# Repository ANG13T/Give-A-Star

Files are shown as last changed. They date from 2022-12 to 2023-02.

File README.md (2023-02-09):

<div style="text-align:center" align="center">
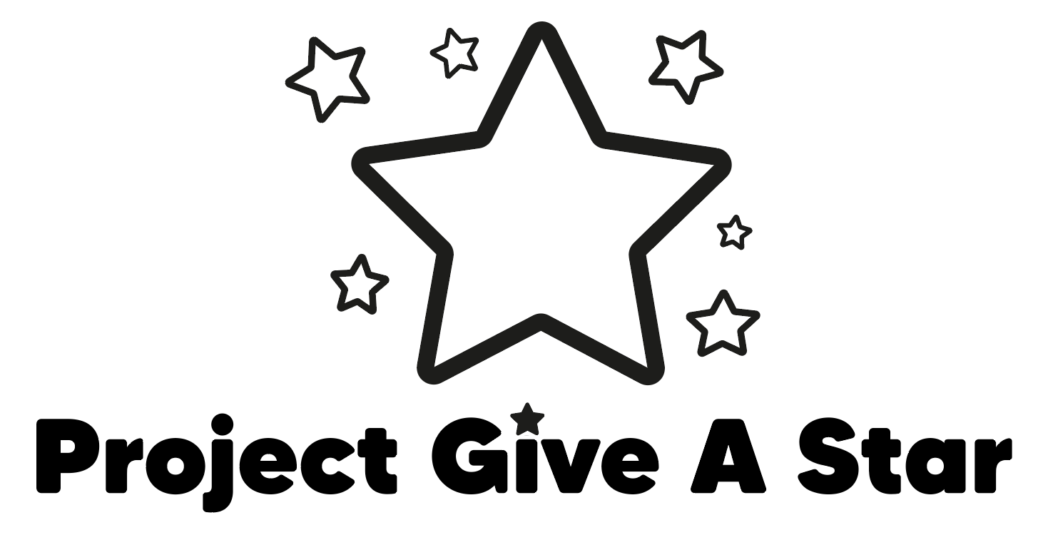
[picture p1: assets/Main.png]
Give A Star logo

</div>

<h3 style="text-align:center" align="center">A Star PCB Board based on the ESP32-S2 and D1 Mini to teach the basics of soldering</h3>

## Features
- Five Different LED Animations
- Change Animations by Clicking Button
- Teach the Basics of Soldering
- Great for Beginners

## Components
| Component | Purpose |
| --- | --- |
| **ESP32-S2** OR **ESP8266 D1 Mini** | Manage animations and code
| 128x64 SSH1106 OLED | Write a visual message to someone |
| Tactile Push Button | Change light animation |
| 6x LED | Display animations |
| 6x 100ohm Resistors | Manage voltage |

## Hardware Setup
**Top LED** 
| LED Pin | ESP32-S2 Pin | D1 Mini Pin |
| --- | --- | --- |
| VIN | 9 | D6 |
| GND | GND | GND |

**Right LED** 
| LED Pin | ESP32-S2 Pin | D1 Mini Pin |
| --- | --- | --- |
| VIN | 7 | D5 |
| GND | GND | GND |

**Bottom Right LED** 
| LED Pin | ESP32-S2 Pin | D1 Mini Pin |
| --- | --- | --- |
| VIN | 5 | D0 |
| GND | GND | GND |

**Left LED** 
| LED Pin | ESP32-S2 Pin | D1 Mini Pin |
| --- | --- | --- |
| VIN | 11 | D7 |
| GND | GND | GND |

**Bottom Left LED** 
| LED Pin | ESP32-S2 Pin | D1 Mini Pin |
| --- | --- | --- |
| VIN | 12 | D8 |
| GND | GND | GND |

**OLED SSH1106** 
| OLED Pin | ESP32-S2 Pin | D1 Mini Pin |
| --- | --- | --- |
| VCC | 3V3 | 3V3 |
| GND | GND | GND |
| SCK | 35 | D1 |
| SDA | 33 | D2 |

**Push Button** 
| Button Pin | ESP32-S2 Pin | D1 Mini Pin |
| --- | --- | --- |
| 1 | 3V3 | 3V3 |
| 2 | 16 | D4 |
| 2 | GND | GND |

## Breadboard
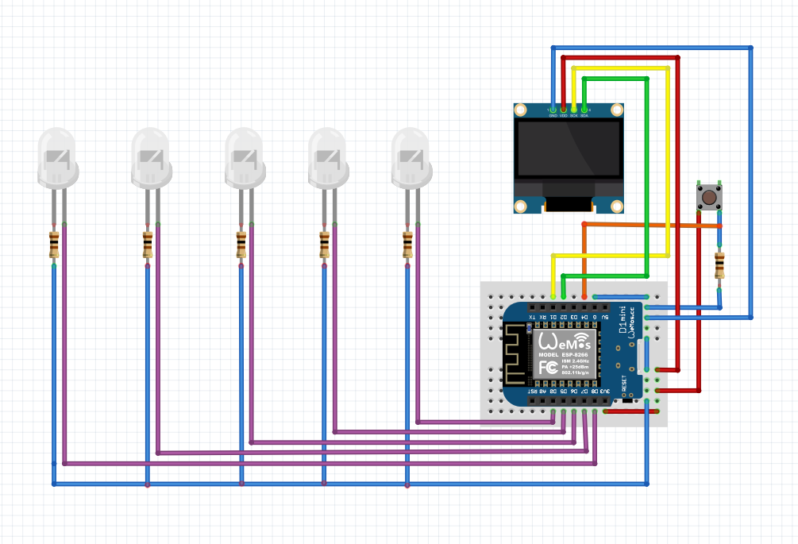
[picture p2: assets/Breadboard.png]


## Schematic
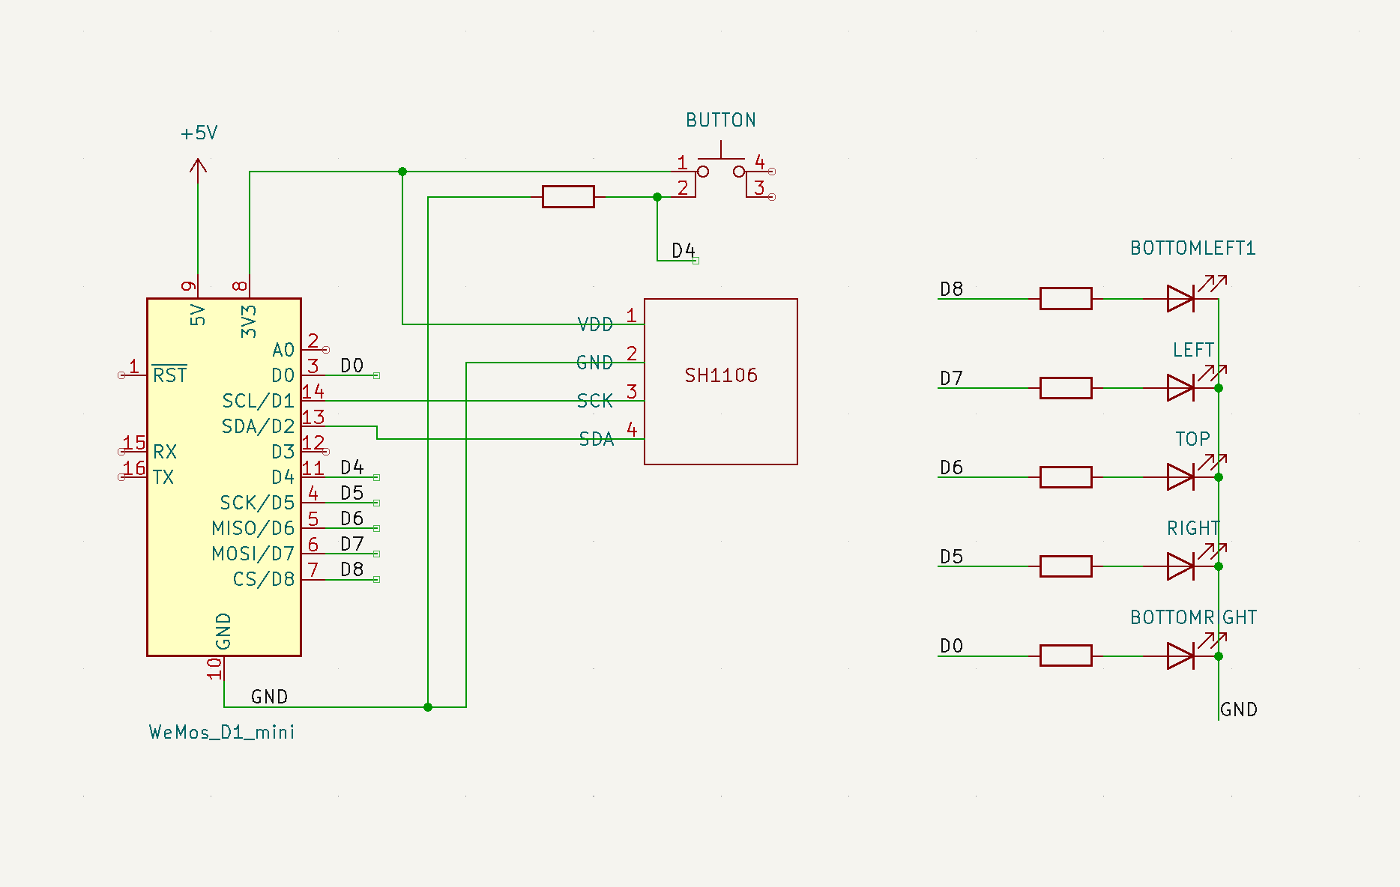
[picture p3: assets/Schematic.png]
Give A Star schematic


## PCB Design
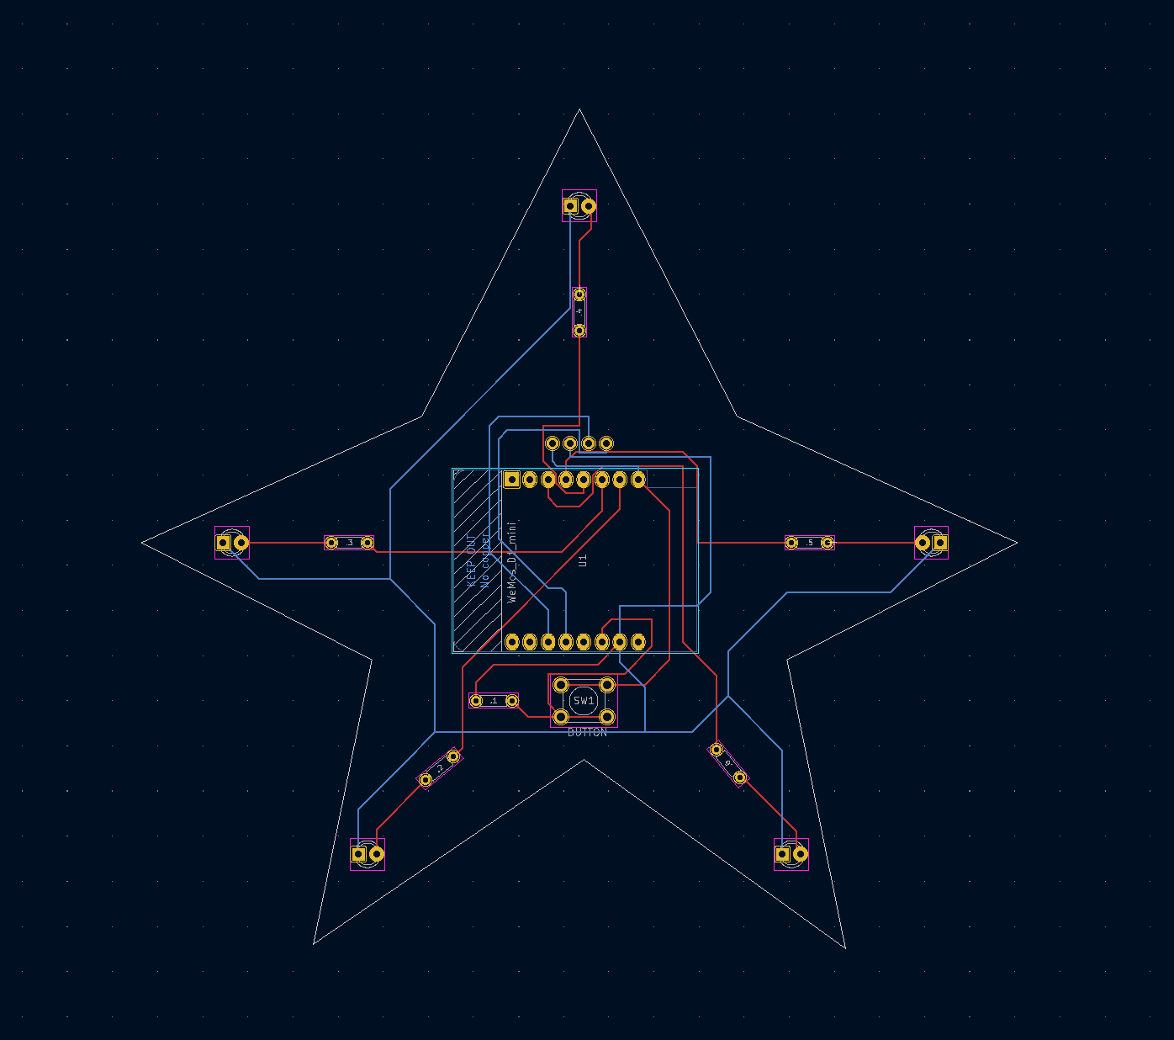
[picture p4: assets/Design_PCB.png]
Give A Star PCB Design


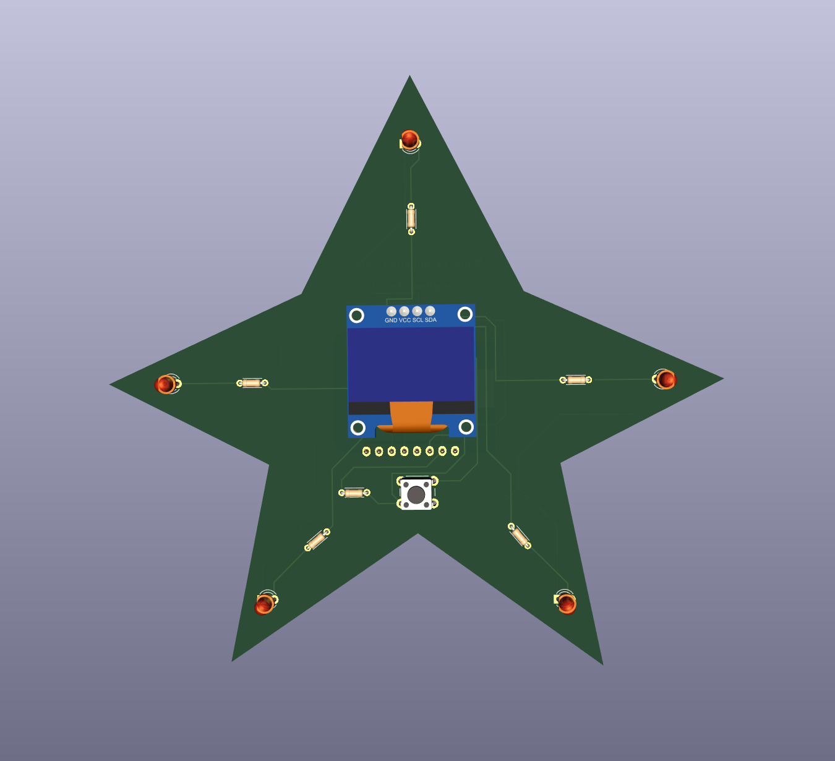
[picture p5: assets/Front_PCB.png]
Give A Star PCB Front
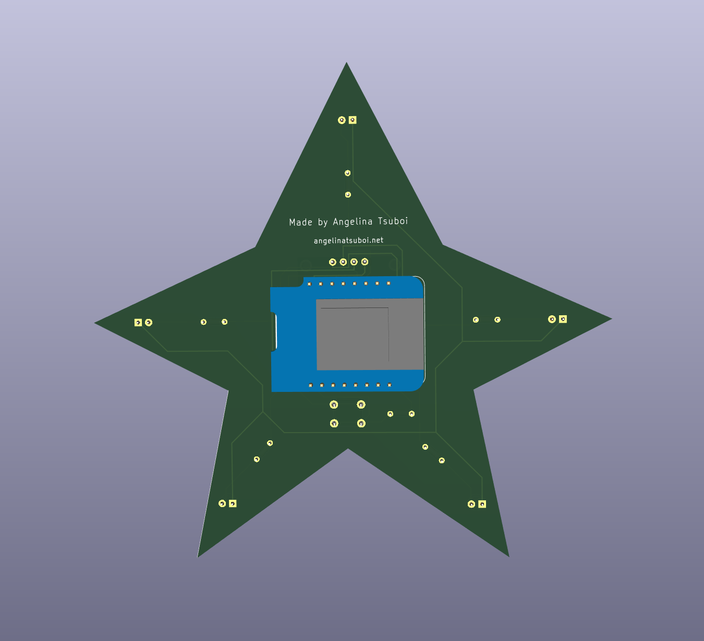
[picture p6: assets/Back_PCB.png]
Give A Star PCB Back


## Photos
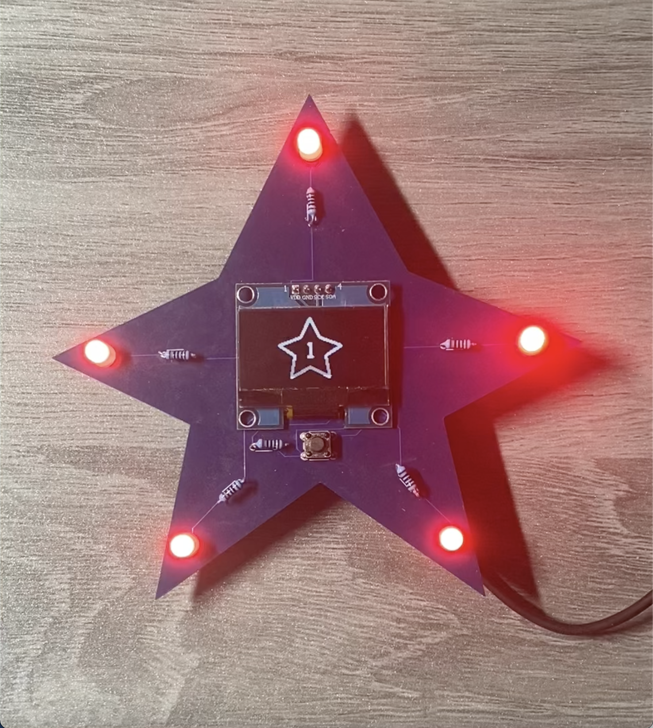
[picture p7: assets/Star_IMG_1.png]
Give A Star Photo 1
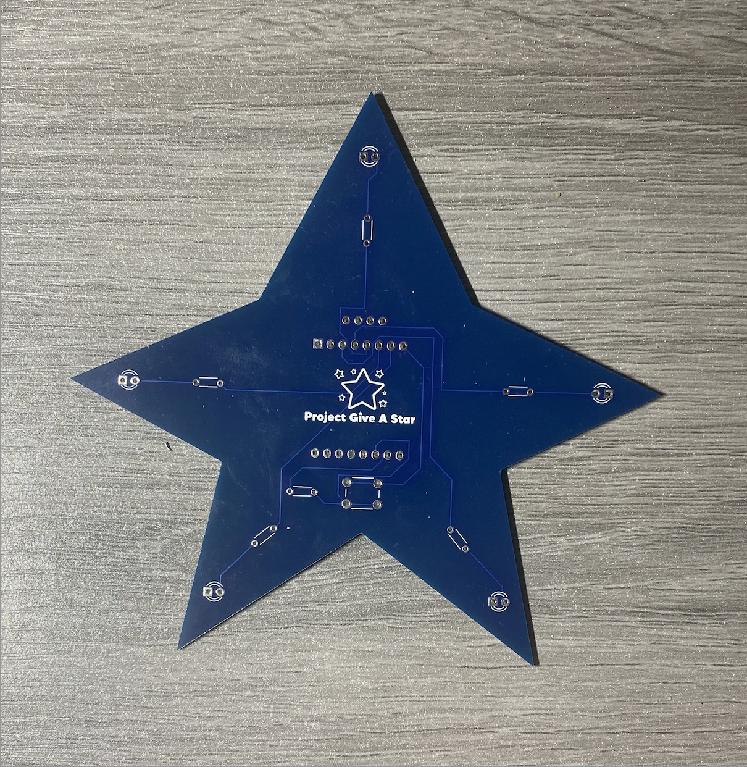
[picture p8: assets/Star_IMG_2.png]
Give A Star Photo 2
&nbsp;&nbsp;

## Set up
- Arduino IDE with the following URL added under Preferences -> Additional board manager URL's: http://arduino.esp8266.com/stable/package_esp8266com_index.json (D1 Mini) OR https://raw.githubusercontent.com/espressif/arduino-esp32/gh-pages/package_esp32_dev_index.json (ESP32-S2)

- ESP8266 boards added in Arduino IDE by going to Tools -> Boards -> Boards Manager, and installing ESP8266 by ESP8266 Community (D1 Mini)

- ESP32 boards added in Arduino IDE by going to Tools -> Boards -> Boards Manager, and installing ESP32 by Expressif Systems (ESP32-S2)

- Install Zip file from https://github.com/wonho-maker/Adafruit_SH1106 and unzip the file inside Arduino -> libraries

- Adafruit GFX library installed in Arduino IDE by going to Sketch -> Include Library -> Manage Libraries and installing "Adafruit GFX Library" by Adafruit

- Optional: Depending on which type of OLED screen you use, you might have to install this library [esp8266-oled-ssd1306](https://github.com/ThingPulse/esp8266-oled-ssd1306) or **SSD1306 by Adafruit:** Sketch -> Include Library -> Manage Libraries and installing "Adafruit GFX Library"

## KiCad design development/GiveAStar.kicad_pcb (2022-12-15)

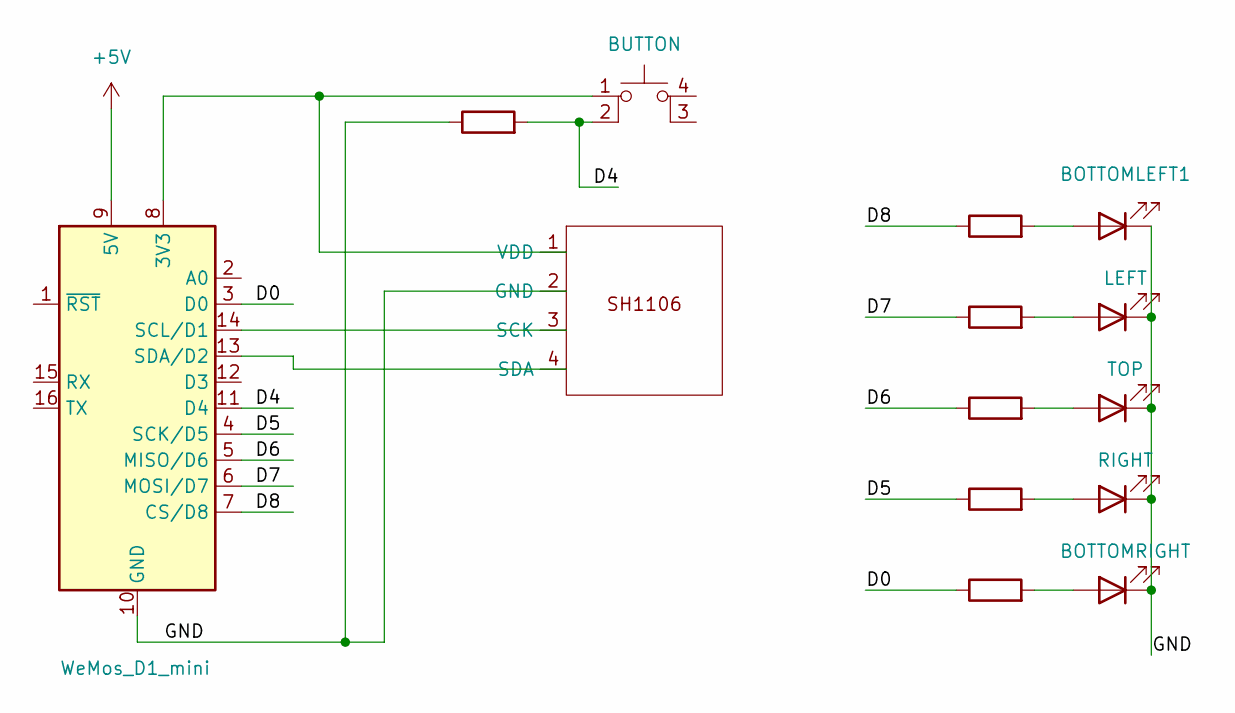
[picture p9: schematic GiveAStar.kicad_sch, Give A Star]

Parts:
.1, .2, .3, .4, .5, .6: R; R_Axial_DIN0204_L3.6mm_D1.6mm_P5.08mm_Horizontal
BOTTOMLEFT1: LEFT; LED_D3.0mm
D1: TOP; LED_D3.0mm
D2: RIGHT; LED_D3.0mm
D3: BOTTOMRIGHT; LED_D3.0mm
D4: LED; LED_D3.0mm
SW1: BUTTON; SW_PUSH_6mm
U1: WeMos_D1_mini; WEMOS_D1_mini_light
U2: SSH1106; Adafruit_SSH1106

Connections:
+5V: U1.9 (5V)
/D0: .6.1, U1.3 (D0)
/D4: .1.2, SW1.2, U1.11 (D4)
/D5: .5.1, U1.4 (SCK/D5)
/D6: .4.1, U1.5 (MISO/D6)
/D7: .3.1, U1.6 (MOSI/D7)
/D8: .2.1, U1.7 (CS/D8)
/GND: .1.1, BOTTOMLEFT1.1 (K), D1.1 (K), D2.1 (K), D3.1 (K), D4.1 (K), U1.10 (GND), U2.2 (GND)
unnamed: .2.2, BOTTOMLEFT1.2 (A)
unnamed: .3.2, D1.2 (A)
unnamed: .4.2, D2.2 (A)
unnamed: .5.2, D3.2 (A)
unnamed: .6.2, D4.2 (A)
unnamed: SW1.1, U1.8 (3V3), U2.1 (VDD)
unnamed: U1.13 (SDA/D2), U2.4 (SDA)
unnamed: U1.14 (SCL/D1), U2.3 (SCK)

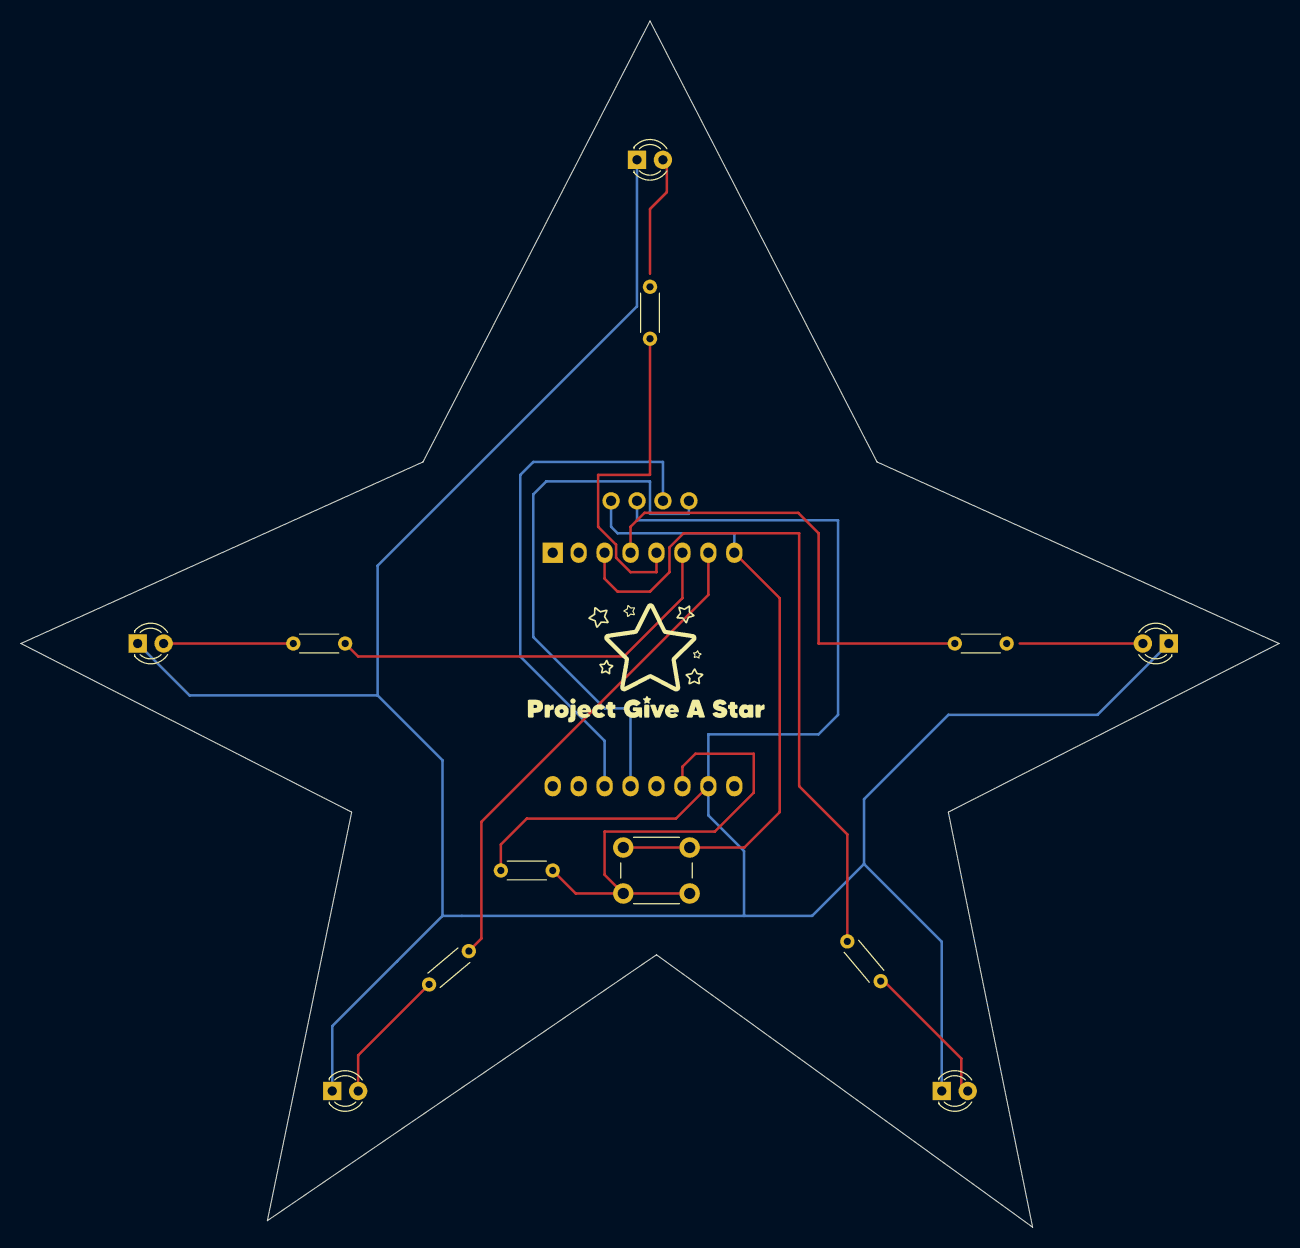
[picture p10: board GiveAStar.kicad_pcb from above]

Board: 2 copper layers, 123.2 x 118.1 mm, 14 parts (1 on the bottom side), 15 nets.

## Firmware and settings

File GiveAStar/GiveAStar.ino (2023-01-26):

#include "SH1106Wire.h"
#include "graphics.h"

SH1106Wire display(0x3C, 33, 35);
const int leds[5] = {5, 7, 9, 11, 12};
const int button = 16;

// 0 = no animation, 1 = in order sequence, 2 = pairs (set starting point), 3 = flashing
int starAnimation = 0;

// variables for animation controls
int selectedLED = 0;
bool isFlashing = true;

// timing controls
long interval = 750; // length of animation interval (milliseconds)
long previousMillis = 0;

void setup() {
  Serial.begin(115200);

  // OLED set up with logo
  display.init();
  display.flipScreenVertically();
  display.setTextAlignment(TEXT_ALIGN_LEFT);
  display.setFont(ArialMT_Plain_10);
  display.drawXbm(5, 5, logo_width, logo_height, logo);
  display.display();
  display.setTextAlignment(TEXT_ALIGN_CENTER);

  // LED set up
  for (int i = 0; i < 5; i++) {
    pinMode(leds[i], OUTPUT);
  }
  
  pinMode(button, INPUT);
  delay(1000);
  display.clear();
}

void loop() {
  int pushed = digitalRead(button);
  unsigned long currentMillis = millis();

  // button input code (sets animation number)
  if (pushed == HIGH) {

    if (starAnimation == 3) {
      starAnimation = 0;
    } else  {
      starAnimation += 1;
      if (starAnimation == 2) {
        selectedLED = 0;
      }
    }
    
    resetLEDs();
    delay(500);
  }

  if (currentMillis - previousMillis > interval) {
    // save the last time you blinked the LED
    previousMillis = currentMillis;

    if (starAnimation == 0) {
      // Animation 1: All LEDs on
      showStarImage(0);
      for (int i = 0; i < 5; i++) {
        digitalWrite(leds[i], HIGH);
      }
      
    } else if (starAnimation == 1) {
      // Animation 2: One LED at a time sequence
      showStarImage(1);
      digitalWrite(leds[selectedLED], HIGH);
      digitalWrite(leds[getPrevLED(selectedLED)], LOW);
      selectedLED = getNextLED(selectedLED);
      
    } else if (starAnimation == 2) {
       // Animation 3: LED pairs animation
      showStarImage(2);
      if (selectedLED == 0) {
        digitalWrite(leds[2], HIGH); // top led
      } else if (selectedLED == 1) {
        digitalWrite(leds[1], HIGH); // middle leds
        digitalWrite(leds[3], HIGH);
      } else {
        digitalWrite(leds[0], HIGH); // bottom leds
        digitalWrite(leds[4], HIGH);
      }
      selectedLED = getNextLEDPairs(selectedLED);
      
    } else {
      // Animation 4: Flashing LEDs
      showStarImage(3);
      if (isFlashing) {
        for (int i = 0; i < 5; i++) {
          digitalWrite(leds[i], HIGH);
        }
      } else {
        for (int i = 0; i < 5; i++) {
          digitalWrite(leds[i], LOW);
        }
      }
      isFlashing = !isFlashing;
    }
    
  }
}

// Helper Functions

// shows the star graphic indicating animation number
void showStarImage(int animation) {
  display.clear();
  if (animation == 0) {
    display.drawXbm(30, 2, Star_1_width, Star_1_height, Star_1_image);
  } else if (animation == 1) {
    display.drawXbm(30, 2, Star_2_width, Star_2_height, Star_2_image);
  } else if (animation == 2) {
    display.drawXbm(30, 2, Star_3_width, Star_3_height, Star_3_image);
  } else {
    display.drawXbm(30, 2, Star_4_width, Star_4_height, Star_4_image);
  }
  
  display.display();
}

// gets previous LED in sequence
int getPrevLED(int val) {
  if (val == 0) {
    return 4;
  } else {
    return val - 1;
  }
}

// gets next LED in sequence
int getNextLED(int val) {
  if (val == 4) {
    return  0;
  } else {
    return val + 1;
  }
}

// gets next LED pairs in sequence
int getNextLEDPairs(int val) {
  if (val == 2) {
    return 0;
  } else {
    return val + 1;
  }
}

// turns off all LEDs
void resetLEDs() {
  for (int i = 0; i < 5; i++) {
    digitalWrite(leds[i], LOW);
  }
}

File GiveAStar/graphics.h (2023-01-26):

#define logo_width 117
#define logo_height 60
static unsigned char logo[] = {
   0x00, 0x00, 0x00, 0x00, 0x00, 0x00, 0x00, 0x00, 0x00, 0x00, 0x00, 0x00,
   0x00, 0x00, 0x00, 0x00, 0x00, 0x00, 0x00, 0x00, 0x00, 0x00, 0x38, 0x00,
   0x00, 0x00, 0x00, 0x00, 0x00, 0x00, 0x00, 0x00, 0x00, 0x00, 0x00, 0x00,
   0x06, 0x7c, 0x00, 0xc4, 0x00, 0x00, 0x00, 0x00, 0x00, 0x00, 0x00, 0x00,
   0x00, 0x06, 0x00, 0x11, 0x6c, 0x00, 0xb4, 0x00, 0x00, 0x00, 0x00, 0x00,
   0x00, 0x00, 0x00, 0x00, 0xf8, 0x80, 0x00, 0xe6, 0x00, 0x84, 0x00, 0x00,
   0x00, 0x00, 0x00, 0x00, 0x00, 0x00, 0x00, 0x42, 0x00, 0x11, 0xc6, 0x00,
   0x84, 0x01, 0x00, 0x00, 0x00, 0x00, 0x00, 0x00, 0x00, 0x00, 0x41, 0x00,
   0x0a, 0xc7, 0x01, 0x04, 0x03, 0x00, 0x00, 0x00, 0x00, 0x00, 0x00, 0x00,
   0xc0, 0x40, 0x00, 0x02, 0x83, 0x01, 0x06, 0x01, 0x00, 0x00, 0x00, 0x00,
   0x00, 0x00, 0x00, 0x40, 0x40, 0x00, 0x80, 0x81, 0x01, 0x50, 0x00, 0x00,
   0x00, 0x00, 0x00, 0x00, 0x00, 0x00, 0x00, 0x82, 0x00, 0x80, 0x01, 0x03,
   0x60, 0x00, 0x00, 0x00, 0x00, 0x00, 0x00, 0x00, 0x00, 0x00, 0xf2, 0x00,
   0xc0, 0x01, 0x03, 0x20, 0x00, 0x00, 0x00, 0x00, 0x00, 0x00, 0x00, 0x00,
   0x00, 0x0e, 0x00, 0xc0, 0x00, 0x06, 0x00, 0x00, 0x00, 0x00, 0x00, 0x00,
   0x00, 0x00, 0x00, 0x00, 0x04, 0x00, 0x60, 0x00, 0x06, 0x00, 0x00, 0x00,
   0x00, 0x00, 0x00, 0x00, 0x00, 0x00, 0x00, 0x00, 0x00, 0x60, 0x00, 0x0c,
   0x00, 0x00, 0x00, 0x00, 0x00, 0x00, 0x00, 0x00, 0x00, 0x00, 0x00, 0x80,
   0x3f, 0x00, 0xfc, 0x01, 0x00, 0x00, 0x00, 0x00, 0x00, 0x00, 0x00, 0x00,
   0x00, 0x00, 0xff, 0x3f, 0x00, 0xf0, 0xff, 0x00, 0x00, 0x00, 0x00, 0x00,
   0x00, 0x00, 0x00, 0x00, 0x80, 0x3f, 0x00, 0x00, 0x00, 0xfe, 0x03, 0x00,
   0x00, 0x00, 0x00, 0x00, 0x00, 0x00, 0x00, 0xc0, 0x00, 0x00, 0x00, 0x00,
   0x00, 0x07, 0x00, 0x00, 0x00, 0x00, 0x00, 0x00, 0x00, 0x00, 0xc0, 0x01,
   0x00, 0x00, 0x00, 0x00, 0x07, 0x00, 0x00, 0x00, 0x00, 0x00, 0x00, 0x00,
   0x00, 0x80, 0x03, 0x00, 0x00, 0x00, 0x80, 0x03, 0x00, 0x00, 0x00, 0x00,
   0x00, 0x00, 0x00, 0x00, 0x00, 0x07, 0x00, 0x00, 0x00, 0xc0, 0x01, 0x00,
   0x00, 0x00, 0x00, 0x00, 0x00, 0x00, 0x00, 0x00, 0x0e, 0x00, 0x00, 0x00,
   0xe0, 0x00, 0x00, 0x00, 0x00, 0x00, 0x00, 0x00, 0x00, 0x00, 0x00, 0x1c,
   0x00, 0x00, 0x00, 0x70, 0x00, 0x00, 0x00, 0x00, 0x00, 0x00, 0x00, 0x00,
   0x00, 0x00, 0x38, 0x00, 0x00, 0x00, 0x38, 0x00, 0x00, 0x00, 0x00, 0x00,
   0x00, 0x00, 0x00, 0x00, 0x00, 0x70, 0x00, 0x00, 0x00, 0x1c, 0x0c, 0x00,
   0x00, 0x00, 0x00, 0x00, 0x00, 0x00, 0x00, 0x00, 0xe0, 0x00, 0x00, 0x00,
   0x0e, 0x12, 0x00, 0x00, 0x00, 0x00, 0x00, 0x00, 0x00, 0x00, 0x00, 0xc0,
   0x01, 0x00, 0x00, 0x07, 0x04, 0x00, 0x00, 0x00, 0x00, 0x00, 0x00, 0x00,
   0x00, 0x00, 0x80, 0x03, 0x00, 0x80, 0x03, 0x08, 0x00, 0x00, 0x00, 0x00,
   0x00, 0x00, 0x00, 0x00, 0x80, 0x00, 0x03, 0x00, 0x80, 0x01, 0x00, 0x00,
   0x00, 0x00, 0x00, 0x00, 0x00, 0x00, 0x00, 0xc0, 0x00, 0x03, 0x00, 0x80,
   0x01, 0x00, 0x00, 0x00, 0x00, 0x00, 0x00, 0x00, 0x00, 0x00, 0x30, 0x81,
   0x01, 0x00, 0x80, 0x01, 0x00, 0x00, 0x00, 0x00, 0x00, 0x00, 0x00, 0x00,
   0x00, 0x10, 0x82, 0x01, 0x00, 0x80, 0x01, 0x00, 0x00, 0x00, 0x00, 0x00,
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

   #define Star_1_width 64
#define Star_1_height 61
static unsigned char Star_1_image[] = {
   0x00, 0x00, 0x00, 0x80, 0x01, 0x00, 0x00, 0x00, 0x00, 0x00, 0x00, 0xc0,
   0x03, 0x00, 0x00, 0x00, 0x00, 0x00, 0x00, 0xe0, 0x03, 0x00, 0x00, 0x00,
   0x00, 0x00, 0x00, 0xe0, 0x07, 0x00, 0x00, 0x00, 0x00, 0x00, 0x00, 0xf0,
   0x07, 0x00, 0x00, 0x00, 0x00, 0x00, 0x00, 0xf0, 0x0f, 0x00, 0x00, 0x00,
   0x00, 0x00, 0x00, 0x78, 0x0e, 0x00, 0x00, 0x00, 0x00, 0x00, 0x00, 0x78,
   0x1e, 0x00, 0x00, 0x00, 0x00, 0x00, 0x00, 0x3c, 0x1c, 0x00, 0x00, 0x00,
   0x00, 0x00, 0x00, 0x3c, 0x3c, 0x00, 0x00, 0x00, 0x00, 0x00, 0x00, 0x1c,
   0x38, 0x00, 0x00, 0x00, 0x00, 0x00, 0x00, 0x1e, 0x78, 0x00, 0x00, 0x00,
   0x00, 0x00, 0x00, 0x0e, 0x70, 0x00, 0x00, 0x00, 0x00, 0x00, 0x00, 0x0f,
   0xf0, 0x00, 0x00, 0x00, 0x00, 0x00, 0x00, 0x07, 0xe0, 0x00, 0x00, 0x00,
   0x00, 0x00, 0x80, 0x07, 0xe0, 0x01, 0x00, 0x00, 0x00, 0x00, 0x80, 0x03,
   0xc0, 0x01, 0x00, 0x00, 0x00, 0x00, 0xc0, 0x03, 0xc0, 0x03, 0x00, 0x00,
   0x00, 0x00, 0xc0, 0x01, 0x80, 0x03, 0x00, 0x00, 0x00, 0x00, 0xf0, 0x01,
   0x80, 0x0f, 0x00, 0x00, 0x00, 0x00, 0xfe, 0x00, 0x00, 0x3f, 0x00, 0x00,
   0x00, 0x80, 0x7f, 0x00, 0x00, 0xfe, 0x01, 0x00, 0x00, 0xf0, 0x1f, 0x00,
   0x00, 0xf8, 0x07, 0x00, 0x00, 0xfe, 0x03, 0x00, 0x00, 0xe0, 0x3f, 0x00,
   0xc0, 0x7f, 0x00, 0x00, 0x00, 0x00, 0xff, 0x01, 0xf8, 0x1f, 0x00, 0xc0,
   0x03, 0x00, 0xf8, 0x07, 0xfe, 0x03, 0x00, 0xe0, 0x03, 0x00, 0xe0, 0x3f,
   0x7f, 0x00, 0x00, 0xe0, 0x03, 0x00, 0x00, 0x7f, 0x1f, 0x00, 0x00, 0xc0,
   0x03, 0x00, 0x00, 0xfc, 0x3e, 0x00, 0x00, 0x80, 0x03, 0x00, 0x00, 0xf8,
   0xfc, 0x00, 0x00, 0x80, 0x03, 0x00, 0x00, 0x7e, 0xf0, 0x01, 0x00, 0x80,
   0x03, 0x00, 0x80, 0x1f, 0xe0, 0x07, 0x00, 0x80, 0x03, 0x00, 0xc0, 0x0f,
   0x80, 0x0f, 0x00, 0x80, 0x03, 0x00, 0xf0, 0x03, 0x00, 0x3f, 0x00, 0x80,
   0x03, 0x00, 0xf8, 0x01, 0x00, 0x7e, 0x00, 0x80, 0x03, 0x00, 0x7e, 0x00,
   0x00, 0xf8, 0x00, 0x80, 0x03, 0x00, 0x1f, 0x00, 0x00, 0xf0, 0x03, 0x80,
   0x03, 0x80, 0x0f, 0x00, 0x00, 0xc0, 0x03, 0xe0, 0x07, 0xc0, 0x03, 0x00,
   0x00, 0x80, 0x03, 0xe0, 0x0f, 0xc0, 0x01, 0x00, 0x00, 0x80, 0x03, 0xe0,
   0x07, 0xc0, 0x01, 0x00, 0x00, 0x80, 0x03, 0x00, 0x00, 0xc0, 0x03, 0x00,
   0x00, 0xc0, 0x03, 0x00, 0x00, 0x80, 0x03, 0x00, 0x00, 0xc0, 0x01, 0x00,
   0x00, 0x80, 0x03, 0x00, 0x00, 0xc0, 0x01, 0x00, 0x00, 0x80, 0x03, 0x00,
   0x00, 0xc0, 0x01, 0x00, 0x00, 0x80, 0x03, 0x00, 0x00, 0xc0, 0x01, 0x00,
   0x00, 0x80, 0x07, 0x00, 0x00, 0xc0, 0x01, 0x00, 0x00, 0x80, 0x07, 0x00,
   0x00, 0xe0, 0x01, 0x80, 0x01, 0x00, 0x07, 0x00, 0x00, 0xe0, 0x00, 0xe0,
   0x07, 0x00, 0x07, 0x00, 0x00, 0xe0, 0x00, 0xf8, 0x1f, 0x00, 0x07, 0x00,
   0x00, 0xe0, 0x00, 0xfe, 0x7f, 0x00, 0x07, 0x00, 0x00, 0xe0, 0x80, 0x3f,
   0xfc, 0x01, 0x0f, 0x00, 0x00, 0xe0, 0xc0, 0x0f, 0xf0, 0x07, 0x0e, 0x00,
   0x00, 0xf0, 0xf0, 0x07, 0xc0, 0x1f, 0x0e, 0x00, 0x00, 0x70, 0xfc, 0x01,
   0x00, 0x7f, 0x0e, 0x00, 0x00, 0x70, 0x7f, 0x00, 0x00, 0xfc, 0x0f, 0x00,
   0x00, 0xf0, 0x1f, 0x00, 0x00, 0xf0, 0x0f, 0x00, 0x00, 0xf0, 0x07, 0x00,
   0x00, 0xe0, 0x1f, 0x00, 0x00, 0xf0, 0x01, 0x00, 0x00, 0x80, 0x0f, 0x00,
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

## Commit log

2022-12-07 feat: init button input
2022-12-08 feat: init button func
2022-12-08 feat: init basic led logic
2022-12-08 feat: init all led sequences
2022-12-10 fix: in order animation
    [GiveAStar.ino]
2022-12-15 Init LED Pinouts
2022-12-15 Init OLED Pin Outs
2022-12-15 Init Push Button Pin Outs
2022-12-15 feat: init development
    [GiveAStar.kicad_pcb, GiveAStar.kicad_sch]
